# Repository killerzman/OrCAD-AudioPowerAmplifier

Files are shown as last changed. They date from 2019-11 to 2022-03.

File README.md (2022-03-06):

# OrCAD Audio Power Amplifier 

OrCAD project of an audio power amplifier implementation. This remained only at a concept stage and was never physically created.

This project was made in year 3 of my university studies at Politehnica University of Bucharest @ Faculty of Electronics, Telecommunications and Information Technology

The implementation was a bit **rushed and unorganized** and some of the documentation is in **Romanian** so **browse at your own risk!**

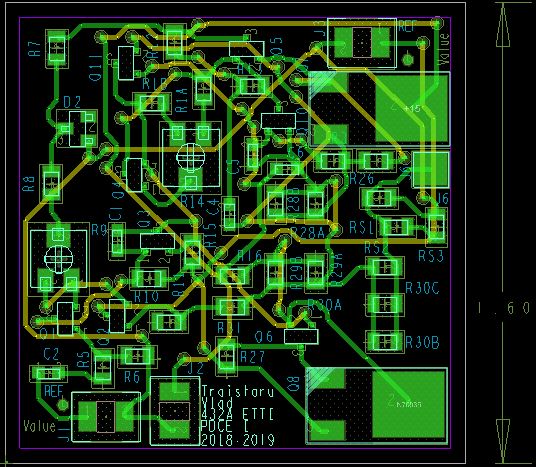
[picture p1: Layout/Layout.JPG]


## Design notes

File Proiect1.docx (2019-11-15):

Trăistaru Vlad-Viorel

Grupa 432A

Amplificatorul audio de putere

PROIECT 1 DCE ETTI

#### AMPLIFICATORUL AUDIO DE PUTERE

Acest capitol prezintă principalele aspectele ale proiectării amplificatoarelor audio de putere. Se porneşte de la o temă de proiectare care stabileşte schema bloc a amplificatorului şi principalii parametri ai amplificatorului. După proiectarea etajului final, pilot, diferenţial, a protecţiei termice şi la scurtcircuit sunt analizate stabilitatea şi amplificarea stabilită de reţeaua de reacţie negativă.

# 1. TEMA DE PROIECTARE

Tema de proiectare se referă la un amplificator de audiofrecvenţă de mare putere realizat dintr-un etaj de ieşire în clasă B polarizat cu ajutorul etajului pilot care lucrează în clasă A. Pentru asigurarea unui curent mare de ieşire tranzistoarele finale sunt realizate din două tranzistoare în conexiune darlington.

Amplificarea în tensiune şi adaptarea cu sursa de semnal de intrare este realizată cu ajutorul etajului de intrare de tip diferenţial care lucrează de asemenea în clasă A. Amplificarea globală a amplificatorului este stabilită prin intermediul reacţiei negative.

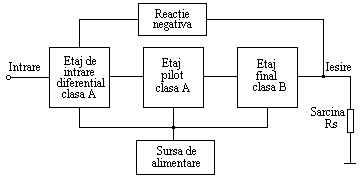
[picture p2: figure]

Figura 2.1 Schema bloc a amplificatorului audio de putere

# 2. SETURI DE DATE DE INTRARE

Principalii parametri ai amplificatorului audio de putere sunt:

- Puterea nominală pe sarcină PS (W)
- Rezistenţa de sarcină Rs (Ω)
- Rezistenţa de intrare Ri (KΩ)
- Amplificarea în tensiune Au (-)

Sursa de alimentare va asigura următorii parametri:

- Curentul nominal Io (mA)
- Rezistenţa de ieşire Ro (Ω)
- Coeficientul de stabilizare
- Tensiunea de alimentare este 220Vac ± 10%

Tabelul 2.1 Seturi de date de intrare pentru proiectare

Nr. | Amplificator | | | | Sursa de alimentare
| PS (W) | Rs (Ω) | Ri (KΩ) | Au (-) | IoM (A) | RoM (Ω)
8 | 10 | 6 | 45 | 10 | 4.1 | 7.2

# 3. ETAJUL FINAL

Este realizat cu două tranzistoare bipolare complementare în conexiune colector comun. Deoarece tehnologia bipolară este axată pe tranzistore de putere de tip npn şi pentru creşterea amplificării în curent a etajului final se utilizează pentru cele două tranzistoare finale de putere configuraţii darlington de tip npn şi pnp.

Figura 2.2 Configuraţie darligton de tip npn

Considerăm T5 şi T7 în regim activ normal RAN.

VBE = VBE5 + VBE7 > 0

>0 >0

=> RAN

VCE = VCE7 = VCE5 + VBE7 > 0

Pentru ICB0 = 0 =>

Ic = Ic5 + Ic7 = βF5 Ib5 + βF7 Ib7 = βF5 Ib5 + βF7 Ie5 =

= = =

= =

≈ ≈

Principalii parametri ai configuraţiei Darlington de tip npn sunt:

βF ≈ βF7 βF5 = mare avantaj

== mare avantaj

VCE, Saturaţie = VCE2, Saturaţie = nemodificată avantaj

VBE = 2VBE5 = 2VBE7 = mare dezavantaj

Figura 2.3 Configuraţie darligton de tip pnp

Considerăm T1 şi T2 in RAN.

VEB = VEB6 > 0

=> RAN

VEC = VCE8 = VEC6 + VBE8 > 0

Pentru ICB0 = 0 =>

IC = IE8 = ( βF8 + 1 ) IB8 = ( βF8 + 1 ) IC6 =

= ( βF8 + 1 ) βF6 IB6 = ( βF8 + 1 ) βF6 IB

βF = (I_C)/(I_B) = ( βF8 + 1 ) βF6 ≈ βF8 βF6

Principalii parametri ai configuraţiei Darlington de tip pnp sunt:

βF ≈ βF8 βF6 = mare avantaj

h11 = h116 = nemodificat avantaj

VEB = VEB6 = nemodificat avantaj

VEC = VCE8 = VEC6 + VBE8 = mare dezavantaj

Când T6 se saturează se pierde controlul lui IC6 prin IB6 iar IC6 se închide prin joncţiunea BE a lui T8 care rămâne în RAN. =>

VEC, Saturaţie = VECT6, Saturaţie + VBET8 = 0,2 + 0,6 = 0,8V

Tehnologia bipolară standard este orientată pe fabricarea tranzistoarelor de tip npn care au conducţie verticală şi au factorul de amplificare în curent βF = mare (100 ÷ 200). Tranzistoarele pnp sunt de tip lateral cu conducţie orizontală sau tranzistor de substrat cu condiţie verticală având βF mic.

În practică se folosesc configuraţiile darlington cu rezistenţă în paralel cu joncţiunea bază-emitor a tranzistorului bipolar de putere de tip npn (R26 şi R27). Rolul acestor rezistenţe este următorul:

- La funcţionarea în clasă „B” în repaus curentul prin T7 este mic iar curentul de baza va fi şi el mic. La curenţi mici de colector amplificarea în curent a tranzistoarelor are o cădere pronunţată Þ amplificarea este redusă Þ reacţia negativă va fi ineficientă asupra neliniarităţii curbei de transfer. La îmbinarea caracteristicilor tranzistoarelor complementare apar distorsiuni de trecere (cross-over) şi pentru micşorarea acestora se face o polarizare iniţială în regim static al tranzistoarelor. Rezistenţa R26 măreşte curentul de colector al tranzistorului T5 în regim de repaus deoarece la IC7 mic ,h11T7 e foarte mare şi cea mai mare a curentului dat de T5 trece prin R26 si astfel T7 lucrează la curenţi acceptabili cu βF7 suficient de mare. La curenţi IC7 mari h11T7 scade exponenţial la creşterea curentului dat de T7 şi R26 se poate neglija.
- Rezistenţa R26 permite evacuarea sarcinii stocate prin circulaţia unui curent invers de bază în perioada corespunzătoare blocării Þ R26 îmbunătăţeşte funcţionarea la frecvenţe înalte dar nu elimină efectele dacă frecvenţa de lucru e mai mare ca fβ.

##### Puterea disipată de tranzistorii finali T7,T8

##### Puterea maximă ce se poate obţine la ieşire este:

##### P_0 =E_C ⋅I_(CM)

EC este tensiunea de alimentare pentru un tranzistor final

ICM este curentul de colector maxim al tranzistorilor finali

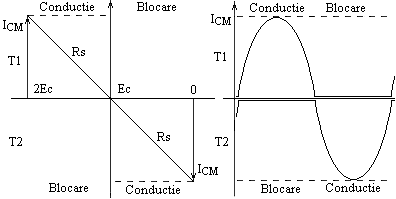
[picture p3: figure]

Figura 2.4 Diagramele de funcţionare a etajului final în contratimp

Puterea absorbită de la sursa de alimentare este:

P_a =2E_C ⋅I_(med)

Imed este curentul mediu absorbit de la sursă

Imed = = k

k este factorul de utilizare a tensiunii de alimentare

P_a =2E_C ⋅I_(med) =2E_C ⋅k⋅(I_(CM))/π=(2k)/π⋅P_0 =0,636⋅k⋅P_0

Puterea nominală pe sarcină are expresia:

P_S =1/2⋅R_S ⋅(k⋅I_(CM) )^2 =1/2⋅R_S ⋅k^2 ⋅I^2 _(CM) =0,5⋅k^2 ⋅P_0

RS este rezistenţa de sarcină

Puterea disipată de tranzistorii finali este:

P_(d(T_7 +T_8 )) =P_a -P_u =(0,636k-0,5k^2 )⋅P_0

Randamentul η=(P_S)/(P_a)=(0,5⋅k^2 ⋅P_0)/(0,636⋅k⋅P_0)=0,785⋅k

Derivând expresia puterii disipate de tranzistorii finali în raport cu k Þ puterea disipată maximă pe tranzistorii finali P_(dmax(T7+T8)) la k=0,636.

Pentru k=0,636 Þ

P_(dmax(T7+T8)) =[0,636^2 -0,5⋅(0,636)^2 ]⋅P_0 =0,2⋅P_0

Pentru un singur tranzistor final

P_(dmaxT7,T8) =1/2⋅(0,636⋅k-0,5⋅k^2 )⋅P_0 , pentru k=0.636 Þ

P_(dmaxT7,T8) =0,1⋅P_0

###### Dimensionarea componentelor etajului final

Pentru dimensionarea componentelor etajului final se impun condiţiile:

- Puterea nominală pe sarcină PS la o frecvenţă convenabilă, respectiv 1kHz (din setul de date utilizate pentru exemplificare PS =60)
- Impedanţa de sarcină nominală la 1kHz are caracter predominant rezistiv RS (din setul de date utilizate pentru exemplificare RS =4Ω)

1. Determinarea valorilor de vârf ale curentului şi tensiunii pe sarcină

P_S =(I_S 2 ⋅R_S)/2=(I_S ⋅U_S)/2⇒I_S =√((2⋅P_S)/(R_S))=√((2⋅10)/6)=1,82A

U_S =R_S ⋅I_S =6Ω⋅1,82A=12,64V≈10,9V

2. Se admite o pierdere de putere de maxim 10% pe rezistenţele de emitor R28 şi R29

R_28 =R_29 =0,47Ω < 0.1 X 6Ω

toleranţă ± 1%

Căderea maximă de tensiune pe R28, R29 este

U_(R_28) =U_(R_29) =R_28 ⋅I_S =0,47 ⋅ 1,82A = 0,85V

P_(dR28,R29) =(I_S ⋅U_(R_28))/4=0,38W (valoare medie, T7,T8 lucrează în clasă B). Se aleg R28 şi R29 de 0,5W (4x 0,125 W fiecare).

3. Se alege rezistenţa pentru circuitul de protecţie la suprasarcină

R_30 =0,157Ω U_(R30) =R_30 ⋅I_S =0,28V P_(dR30) =(Is⋅U_(R30))/2=0,26W

Se alege R30 de 0.375W (3x 0.125W fiecare).

4. Se aleg tranzistorii finali

S-a optat pentru tranzistori finali bipolari de putere de tip MJD31C având următorii parametri:

P_(tot) =15W UCE0,UCER = 100V I_C =3A

h21E = 25-50 (la IC=2A) UBE < 1V UCES = 1.2V

ft = 3Mhz

Ptot este puterea totală disipată

UCE0 este tensiunea colector emitor cu baza în gol

UCER este tensiunea colector emitor cu rezistenţă specificată între bază şi emitor

IC este curentul de colector

h21E este factorul de amplificare în curent static în conexiunea emitor comun

UBE este tensiunea bază emitor

UCES este tensiunea colector emitor în saturaţie

ft este frecventa de taiere minima

5. Verificarea la străpugere a trnzistorilor finali

EC ≤ 0,9UCER , EC = 14V ≤ 90= 0,9 VCER

6. Determinarea tensiunii reziduale pe darlingtonul npn

Urez = UCEST5 + UBET7max

În cazul cel mai defavorabil:

β_(T7,T8) =25⇒I_(BT7,T8) =(I_(CT7,T8))/(β_(T7,T8))=(I_S)/(β_(T7,T8))=(1,82A)/25=72,8mA

În funcţie de IBT7,T8 se aleg T5 şi T6 (BC846B, BC856B)

Pentru BC846B, UCEST5 ≈ 0,4V Þ Urez = 0,4 + 1= 1,4V

7. Determinarea tensiunii de alimentare

EC ≥ US + UR30 + UR28 + Urez = 13.005V = EC’

Se alege EC = 14V > EC’

8. Calculul energetic al tranzistorilor finali

P_0 =E_C ⋅I_(CM) =E_C ⋅I_S =25,48W k=(E^(') _C)/(E_C)=13/14=0,92 P_a =0,636⋅k⋅P_0 =14,9W P_S =1/2⋅k^2 ⋅P_0 =10,78W P_d =P_a -P_S =4,12W

(Puterea disipată pe T7 si T8 )

Puterea disipată pe un tranzistor final este maximă pentru k=0,636 este

P_(dmaxT_7) =P_(dmaxT_8) =0,1⋅P_0 =2,54W

În cazul nostru pentru k=0,92 puterea disipată pe un tranzistor final este

PdT7,T8 = 0,5 ( 0,636k – 0,5 k² ) P0 = 2,06W

η=0,785⋅k=0,722

9.Dimensionarea rezistenţelor R26 ,R27

Se aleg R26 ,R27 = 51Ω, toleranţă ± 1%

ICMT5 = IBMT7 + IR26 = IBMT7 + =72,8 mA + (1V)/(51Ω) ≈92,4mA<100mA

ICMT5 este curentul de colector maxim al tranzistorului T5

IBMT7 este curentul de bază maxim al tranzistorului T7

UBRMT7 este tensiunea bază emitor a tranzistorului T7

10. Estimarea sarcini dinamice pentru T5,T6

RST5 = [ h11T7 + βT7 ( RS + R30 + R28 ) ] ║ R_26

h11T7 = (U_(BEMT7))/(I_(BT7)) ≅ 13,7 Ω

RST5 = ( 13,7 + 25 · 6,627 ) ║ 51 = 39,6 Ω

11. Calculul energetic al tranzistorilor complementari

P0 = ICMT5 · EC = 0,0924· 14 = 1,29W

P0_(dmax) =0.1 P0 =0,129W

Tranzistoarele BC846B şi BC856B corespund, având următorii parametri:

I_C =0.1A I_(CM) =0.2A Ib=5mA T_j =150^0 C P_(tot) =0.25W f_T =100MHz R_(th,j-C) ≤100C/W

12. Calculul frecventei de taiere

ωt = β×ωβ

Pentru T7 si T8 fβ ≥ 222-500kHz

Pentru T5 si T6 fβ ≥ 222-454kHz

# 4. ETAJUL PILOT

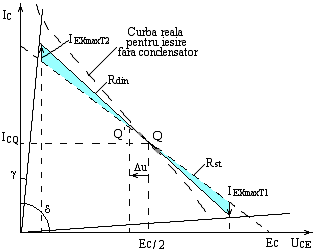
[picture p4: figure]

Figura 2.5 Configuraţia Figura 2.6 Caracteristica de ieşire

etajului pilot ale etajului pilot

Etajul pilot conform cu figura 2.5 este de tip emitor comun EC şi lucrează în clasa A. Pentru utilizarea completă a sursei de alimentare a circuitului de putere este necesară o tensiune de excitaţie vârf la vârf mai mare ca tensiunea de alimentare Uex,vv > EC, condiţie greu de realizat.

În figura 2.6 tgγ=R_(sat) si tgδ=R_(rez) , definite în raport cu ICER. Se observă că în cazul real excursia tensiunii Uex,vv este mult mai mică decât EC şi asimetrică.

K1 şi K2 sunt coeficienţii de utilizare ai tensiunii de alimentare pentru tranzistorul T1 respectiv pentru tranzistorul T2.

În schemele cu ieşire pe condensator, datorită inegalităţii dintre K1 şi K2 (în general K1 < K2) apar distorsiuni la nivele mari şi apare o componentă continuă ( Δu ) ce deplasează punctul static de funcţionare (PSF-ul) în sensul egalizării factorului de utilizare, figura 2.5. În schemele în care ieşirea nu se face pe condensator, ca în cazul acestui proiect, apare o curbură a caracteristicilor.

Soluţia poate fi folosirea unei tensiuni de alimentare a etajului pilot E_p >E_c , fapt ce conduce la complicarea surei de alimentare sau la soluţia de bustrapare a rezistenţei RC.

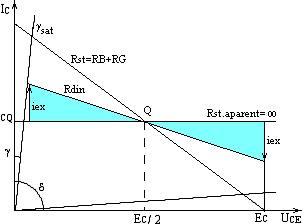
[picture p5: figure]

Figura 2.7 Bustraparea rezistenţei Figura 2.8 Caracteristica de ieşire

de colector a etajului pilot a etajului pilot butstrapat

Pentru acest montaj se poate considera:

- In regim static rezistenţa de alimentare este

R_(st) =R_c =R_B +R_G

- In regim dinamic ZS pentru etajul pilot este Rdin.
- In regim dinamic rezistenţa aparentă de alimentare este Rst a = ∞ şi sursa are valoarea E^(') _C =∞

Avantajele utilizării acestei soluţii sunt următoarele:

- Excursia curentului se limitează la

I_(VV) =2⋅I_(ex) <2⋅I_(CQ)

- Deoarece I_(CQ) >I_(ex) , această soluţie este avantajoasă pentru uşurarea regimului termic al etajului pilot.
- Se obţine astfel

k_1 ≈k_2

Condiţia de funcţionare a schemei este ca rezistenţa dinamică

R_(din) >R_C =R_B +R_G

###### Dimensionarea componentelor etajului pilot

1. Se calculează curentul de excitaţie maxim

I(I_(CT_5 max))/(β_(T_5 min) =(92,4mA)/220=0,42mA)BT_5 max_(exmax)

Se pot neglija curenţii reziduali şi se alege I_(CT3) =I_(CQ) =8mA > I_(exmax) =0,42mA

2. Rezistenţa statică de alimentare

R_C =R_B +R_G =R_13 +R_12 =(E_C)/(I_(CT_3))=(14V)/(8mA)=1,75KΩ

Alegem R_12 =910Ω si R_13 =1k

3. Sarcina dinamică a pilotului

R_(din) ≈(R_13 ⋅h_(11T_6))/(R_13 +h_(11T_6))+(1+h_(21E_f) ⋅(R_13)/(R_13 +h^(') _(11T_6)))(R_S +R_30 )

unde h11T6 = = 687,4Ω şi

h21Ef = h21T6 · h21T8 = 220· 25 = 5500

h^(') _(11T_6) =h_(11T_6) +(1+h_(21E_f) )⋅R_29 = 687,4+ ( 1+5500 ) · 0,47 = 3272,87Ω

Þ R_(din) =(1000⋅687,5)/(1687,5)+(1+5500⋅1/(1+3,2))⋅6.157≈8,476KΩ

Se verifică R_(din) =8,476kΩ>R_B +R_G =1,75KΩ

4. Tensiunea minimă pe tranzistorul pilot

UBEmin,T8_(CEmin,T6) _(pmin)

5. Alegerea tranzistorului pilot

Pentru o funcţionare cât mai bună a botstrapului se alege un tranzistor cu UCEsat şi ICER mici.

Se alege BC846B cu parametri:

I_C =0,1A I_(CM) =0,2A T_j =150^0 C P_(tot) =0,25W f_T =100MHz R_(th,j-C) ≤100C/W

La I_C =2⋅I_(CQ) =16mA→U_(CEsat) =0,6V si I_(CER) =0,2mA

Tensiunea ce trebuie preluata de R15 este

U_(R_15) =UCEsat,T3_15 (U_(R_15))/(I_(CQ))(0,2V)/(8mA)_(p_(min))

Calculele impun alegerea lui R15 = 33Ω cu toleranţă de 1%

6. Curentul de baza al tranzistorului T3

Considerând h21E mediu,T3 = 280 Þ

I_(BT3) =(8mA)/280=28μA

7. Verificarea funcţionării la semnal mic

μ_(BE) =(I_C)/(g_m)=(I_(ex))/(40I_(CQ))= 0,0235V =23.5mV < 26mV = (KT)/q

8. Amplificarea în tensiune a etajului pilot

Etajul pilot este de tip emitor comun cu sarcină distribuită având amplificarea în tensiune:

A_(μp) ≈-(R_(din))/(R_15)=-(8,476k)/(33Ω)=-256,84

9. Calculul frecvenţei de tăiere

ω_T =β_0 ⋅ω_β ⇒ f_(βT_3) ≥0,25..0,625MHz

###### 10. Calculul circuitului de polarizare al tranzistorilor finali

Circuitul de polarizare este alcătuit din tranzistorul T4 ( superdiodă ) şi potenţiometrul R14. Se consideră necesar pentru deschiderea tranzistorilor finali o tensiune de 2 × 0,7V.

Pentru tranzistorul T4 alegem tipul QBC846B având următoarele valori limită absolute:

VCE0 =65V IC = 100mA IB = 5mA

Ptot = 250mW

În PSF tranzistorul T4 are următorii parametri:

I_(C,T4) =8mA U_(CE,T4) ≅1,4V⇒I_(B,T4) =(I_(C,T4))/(h_(21E,T4))≅(8mA)/220=36μA

Se alege prin divizorul de bază curentul:

I_d ≅0,5mA>>I_(B,T4) ⇒R_14 =R_1 +R_2 =(1,4V)/(0,5mA)=2,8kΩ

Se alege R14’ = 2,64kΩ.

R14’ = R1A + R1B + R14(potentiometru)

R14 = 2,2kΩ, R1A = 220Ω, R1B = 220Ω

# 5. ETAJUL DIFERENŢIAL

Etajul diferenţial este alcătuit din două tranzistoare în conexiune EC care lucrează în clasă A şi sunt cuplate diferenţial. Componentele acestui etaj sunt următoarele:

- Tranzistoarele T1 ,T2
- Rezistentele R6, R8, R9, R11, R31 şi D1, R7

Principalele funcţii ale acestui etaj sunt:

- Obţinerea unei impedanţe de intrare convenabile.
- Reglează echilibrarea stării de repaus (în absenţa semnalului) a întregului amplificator de putere
- Permite cuplarea reţelei de reacţie negativă

###### Dimensionarea componentelor etajului diferenţial

1. Alegerea tranzistoarelor T1,T2

Tranzistoarele T1, T2 se aleg de tipul BC856B şi se împerechează (se sortează două tranzistoare cu caracteristici cât mai apropiate). Aceste tranzistoare au următoarele valori limită absolute:

VCE0 =65V IC = 100mA IB = 5mA

Ptot = 250mW Tj = 175°C

2. Dimensionarea rezistenţei de colector a tranzistorului T1 (R11)

Se alege R_(CT_1) =R_11 <Z_(inT3min)

Z21cT_3 _15 11cT_3 min_(inT3min)

IB,T3max ≅ (2I_(CT3))/(ℎ_(21E mediu,T3)) = (2⋅8)/280 = 57µA

IC,T3min ≅ IB,T3max = 57µA Þ = 40 · IC,T3min = 2,3 Þ

h11,T3min = = 160/(2,3) = 69.5K ≅ 70K

Þ Z21cT_3 _15 11cT_3 min_(inT3min) = 70K + 100·0,033K ≅ 103K

Pentru polarizarea bazei lui T3 trebuie ca :

(I_(C,T1) -I_(B,T3) )⋅R_11 =U_(BET3) +U_(R15) ≅ 0,7V + 8mA·33Ω ≅ 0,96V

Din motive de zgomot, pentru a avea factorul de zgomot F = 3dB trebuie ca:

ICT1 ≤ 300µA Se alege ICT1 = ICT2 = 250µA

Þ R_11 ≈(0,96)/(I_(C,T1) -I_(B,T3))=(0,96)/(250-57)=(0,96V)/(193mA)=4,9K

Se alege R11 = 5,6K cu toleranţă de ±1%.

3. Verificarea funcţionării la semnal mic

u_(BE,T1) =(i_(C,T1))/(g_(m,T1))=(i_(C,T1))/(40⋅I_(C,T1))=(80μA)/(40⋅250μA/V)=8mV

4. Determinarea tensiunii stabilizate de D1

Pentru a simula generatorul de curent din emitor trebuie ca tensiunea stabilizată U_z >>u_(BE,T1) . Deoarece I_(BT_1) e foarte mic se poate neglija tensiunea între bază şi masă.

Practic U_z =U_(R8) +U_(BE,T1) +U_(R6) ≈U_(R8) +U_(BE,T1)

Pentru ca R8 să se comporte ca un generator de curent continuu trebuie ca UR8 = ct, dar UBE,T1 variază cu uBE,T1 Þ tensiunea stabilizată de diodă trebuie să fie mult mai mare ca tensiunea bază emitor a tranzistorului T1, UZ >> UBE,T1.

Se alege UZ = 8,2V, astfel UZ ≅ 1000 · UBE,T1

Pentru tranzistorul T1 curentul de colector şi tensiunea colector emitor au valorile:

IC,T1 = 250µA şi U_(CE) ≈E_C =14V .

5. Dimensionarea rezistenţelor R6, R31

Se alege R6 = R31 = 47kΩ, ±5% având în vedere că în jurul acestei valori se va situa Zintr a întregului amplificator.

6. Dimensionarea rezistenţelor R9, R8

Pentru QBC856B din catalog se obţine h21E =220 Þ I_(B,T1) =(250μA)/220≈1μA .

Þ U_(R_6) =47mV . Considerând U_(BE,T1) ≈0,6V

Þ U_(1/2R9) +U_(R_8) =U_z -U_(BE,T1) -U_(R_6) =7,56V

Se alege pentru R9 o valoare de 500Ω şi atunci căderea de tensiune suplimentară pe jumătate din rezistenţa din emitorul lui T1 este :

U_(1/2R9) ≈I_(C,T1) ⋅1/2⋅R_9 =62,5mV Þ UR8 ≅ 7,5V

Curentul prin rezistenţa R8 este suma curenţilor de colector ai tranzistorilor T1, T2 IR8 = 2IC,T1 = 500µA Þ R_8 =(U_(R8))/(I_(R8))=(7,5V)/(0,5mA)=15K Ω, ±1%

7. Polarizarea diodei D1

Alegem o diodă zenner de tipul PL 8,2V care pentru o funcţionare normală trebuie polarizată la Iz =5mA.

R7 = (E_C -U_z)/(I_z +I_(R8))=(14V-8,2V)/(5,5mA) = 1,05KΩ

Se alege R7 = 1 kΩ, ±1%

8. Determinarea amplificării etajului diferenţial

Amplificarea etajului diferenţial poate fi aproximată astfel:

A_(udif) ≅-(R_(Sdif))/(1/2R_9) unde RSdif este rezistenţa de sarcină a diferenţialului

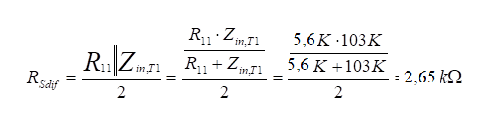
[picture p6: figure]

Þ A_(udif) ≅-(2,65)/(0,25) = -10,6 ≅ -11

# 6. REACŢIA NEGATIVĂ

Se apreciază un factor de transfer pe bucla de reacţie optim la frecvenţe medii:

β_r ≈(R_10)/(R_10 +R_31)≈1/10 (grad de reacţie ≈20dB )

Datorită divizoarelor protecţiei termice, tensiunea reală de intrare pe diferenţial este:

Uin,dif = D1 · D2 · Ugen

Unde: D1 = = 0,95 D2 = = 0,89

Se alege pentru Ugen = 1,5Vef Þ U_(in,dif) =0,95⋅0,89⋅1,5=1,3V_(ef)

Tensiunea nominală de ieşire este :

Un = = 0,7· IS· (RS + R30 ) = 0,7 · 1,82A · (6 + 0,157)Ω = 7,84V

Amplificarea cu reacţie este AUr = = (7,84)/(1,3) = 6,03 = = 1+

Þ = 5,03

Deoarece amplificarea în tensiune în buclă deschisă a amplificatorului de putere este dată de etajul pilot şi etajul diferenţial A_u ≈A_(up) ⋅A_(udif) =-126⋅(-11)=1,386

Practic A_(ur) ≅1/(β_r) Þ R10 ≅ (R_31)/11=(47KΩ)/11=4,27KΩ

Se adoptă R10 = 4,7KΩ, ±1%

Frecvenţa limită pentru T1 şi T2 este fβ ≥ 400 ÷ 800KHz

# 7. LISTA COMPONENTELOR

C1 : 47pF

C2,C3,C4 : 10uF

C5,C6 : 1nF

D2 : BZX84-C8V2

J1,J2,J3 : CON2

J6 : CON1

Q1,Q2,Q6,Q11 : QBC856B

Q3 : QBC817-25

Q4,Q5,Q10 : QBC846B

Q7,Q8 : QMJD31C

Rs1,R28B,R28A,R29B,R29A,R30C,R30B,R30A : 0.47Ω

Rs2 : 1Ω

Rs3 : 4.7Ω

R1B,R1A : 220Ω

R3,R7,R13,R16 : 1KΩ

R5,R14 : 2.2kΩ

R6,R31 : 47kΩ

R8 : 15kΩ

R9 : 500Ω

R10 : 4.7kΩ

R11 : 5.6kΩ

R12 : 910Ω

R15 : 33Ω

R26,R27 : 51Ω

# 8. SCHEMA ELECTRICĂ

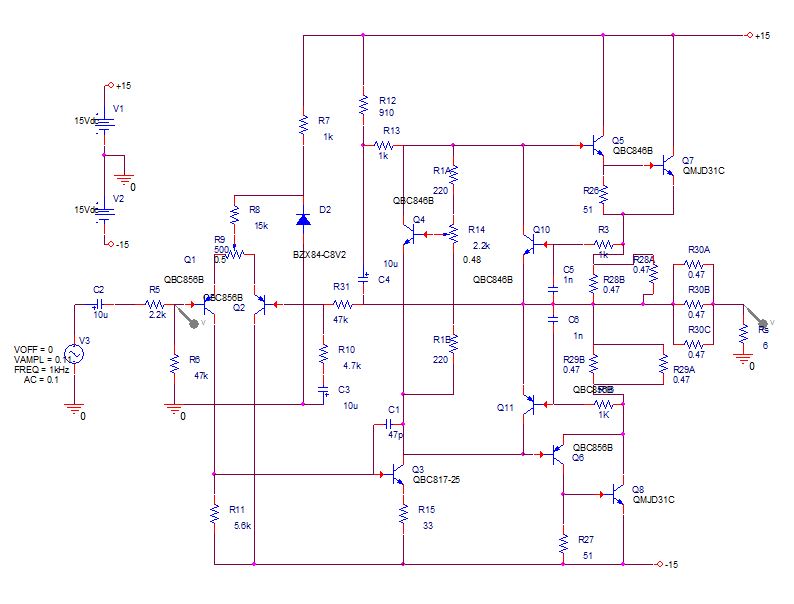
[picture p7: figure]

# 9. ANALIZĂ AC SWEEP

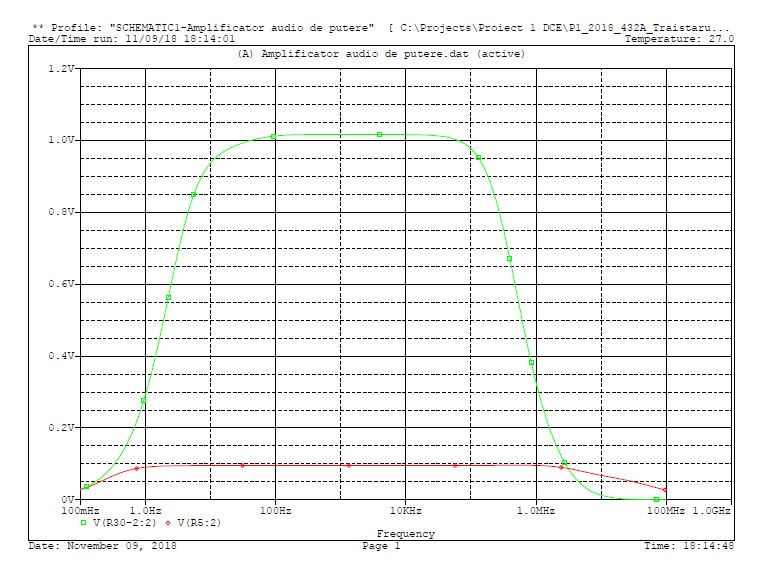
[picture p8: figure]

# 10. ANALIZĂ TIME DOMAIN

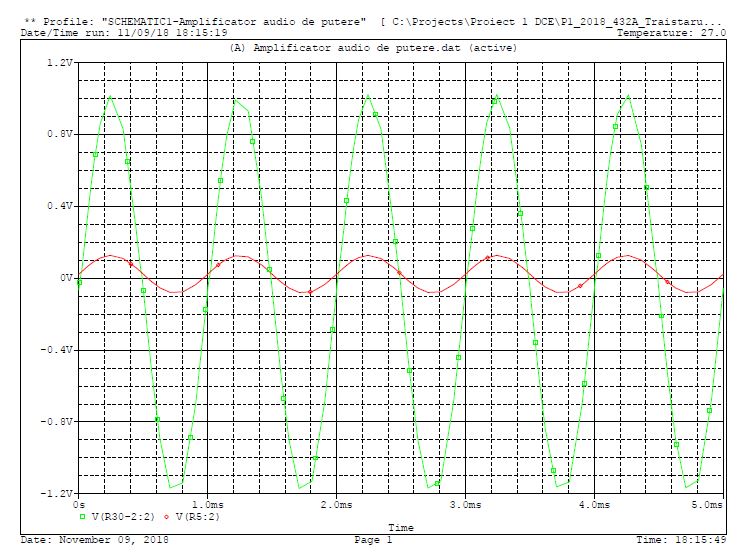
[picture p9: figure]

# 11. ANALIZĂ PSF

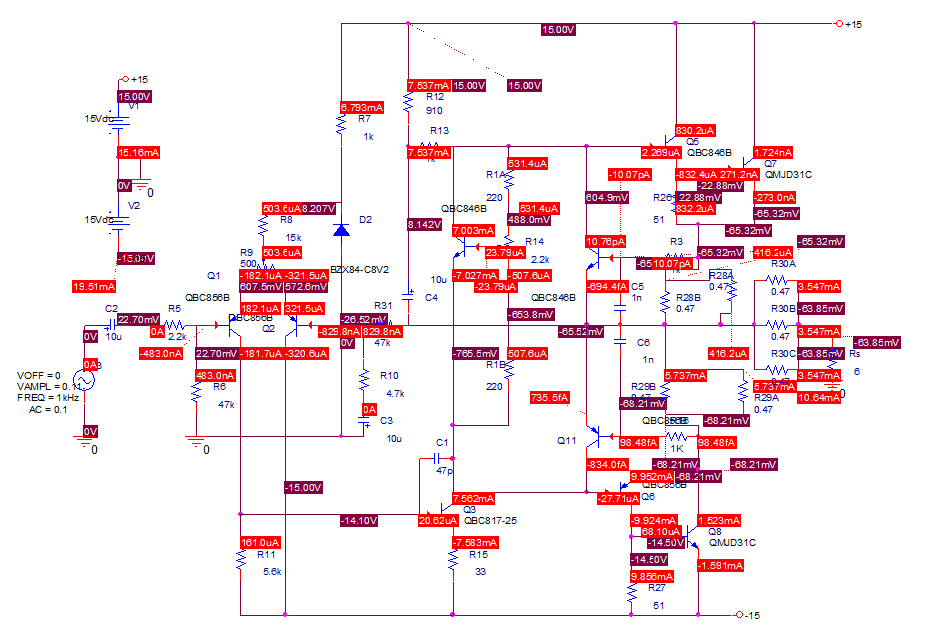
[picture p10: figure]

12. LAYOUT


Proiect 1 DCE ETTI – Amplificatorul audio de putere Trăistaru Vlad-Viorel – 432A

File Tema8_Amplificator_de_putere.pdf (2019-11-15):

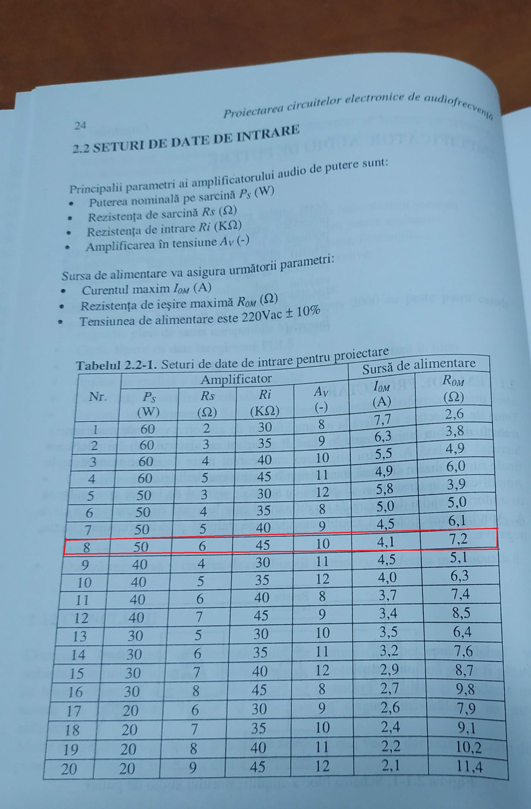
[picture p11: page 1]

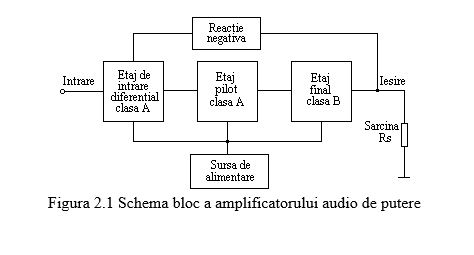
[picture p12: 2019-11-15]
Schema_bloc.JPG

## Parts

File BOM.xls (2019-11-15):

Anexa a1 -Componente SMD disponibile pentru realizarea proiectului P1- tehnlogie SMT- AU 2017-2018
Nr. Crt. | Nume | Catalog | Cod distrib | Nume prod | Prod | Clasă | Qty fix | Qty final | Qty min | Descriere | Distribuitor
1 | 0 ohm | (LINK) (http://www.tme.eu/ro/details/smd1206-0r/rezistente-smd-1206/royal-ohm/1206s4j0000t5e/) | 1206S4J0000T5E | 1206S4J0000T5E | SR PASSIVES | rezistor |  |  |  | Rezistor: thick film; SMD; 1206; 0Ω; 0,25W; ±5%; -55÷125°C | TME România
2 | 0.47 | (LINK) (http://www.tme.eu/ro/details/smd0805-0r47/rezistente-smd-0805/royal-ohm/0805s8j047kt5e/) | SMD0805-0R47 | 0805S8J047KT5E | ROYAL OHM | rezistor | 8 | 8 | 8 | Rezistor SMD, chip, 0805, 0.47Ω, ±5%, 0.125W | TME România
3 | 1 | (LINK) (http://www.tme.eu/ro/details/smd0805-1r-1%25/rezistente-smd-0805/royal-ohm/0805s8f100kt5e/) | SMD0805-1R-1% | 0805S8F100KT5E | ROYAL OHM | rezistor | 1 | 1 | 1 | Rezistor SMD, chip, 0805, 1Ω, ±1%, 0.125W | TME România
4 | 4.7 | (LINK) (http://www.tme.eu/ro/details/smd0805-4r7-1%25/rezistente-smd-0805/royal-ohm/0805waf-4r7-t5e/) | SMD0805-4R7-1% | 0805WAF 4R7 T5E | ROYAL OHM | rezistor | 1 | 1 | 1 | Rezistor SMD, chip, 0805, 4.7Ω, ±1%, 0.125W | TME România
5 | 10 | (LINK) (http://www.tme.eu/ro/details/smd0805-10r-1%25/rezistente-smd-0805/royal-ohm/0805s8f100jt5e/) | SMD0805-10R-1% | 0805S8F100JT5E | ROYAL OHM | rezistor |  |  |  | Rezistor SMD, chip, 0805, 10Ω, ±1%, 0.125W | TME România
6 | 22 | (LINK) (http://www.tme.eu/ro/details/smd0805-22r-1%25/rezistente-smd-0805/royal-ohm/0805s8f220jt5e/) | SMD0805-22R-1% | 0805S8F220JT5E | ROYAL OHM | rezistor |  |  |  | Rezistor SMD, chip, 0805, 22Ω, ±1%, 0.125W | TME România
7 | 33 | (LINK) (http://www.tme.eu/ro/details/smd0805-33r-1%25/rezistente-smd-0805/royal-ohm/0805s8f330jt5e/) | SMD0805-33R-1% | 0805S8F330JT5E | ROYAL OHM | rezistor | 1 | 1 | 1 | Rezistor SMD, chip, 0805, 33Ω, ±1%, 0.125W | TME România
8 | 51 | (LINK) (http://www.tme.eu/ro/details/rc0805jr-0751r/rezistente-smd-0805/yageo/rc0805jr-0751rl/) | SMD0805-51R-1% | 0805S8F510JT5E | ROYAL OHM | rezistor | 2 | 2 | 2 | Rezistor SMD, chip, 0805, 51Ω, ±1%, 0.125W | TME România
9 | 68 | (LINK) (http://www.tme.eu/ro/details/smd0805-68r-1%25/rezistente-smd-0805/royal-ohm/0805s8f680jt5e/) | SMD0805-68R-1% | 0805S8F680JT5E | ROYAL OHM | rezistor |  |  |  | Rezistor SMD, chip, 0805, 68Ω, ±1%, 0.125W | TME România
10 | 82 | (LINK) (https://www.tme.eu/ro/details/rc0805fr-0782r/rezistente-smd-0805/yageo/rc0805fr-0782rl/) | SMD0805-82R-1% | 0805S8F820JT5E | YAGEO | rezistor |  |  |  | Rezistor SMD, chip, 0805, 82Ω, ±1%, 0.125W | TME România
11 | 100 | (LINK) (http://www.tme.eu/ro/details/smd0805-100r-1%25/rezistente-smd-0805/royal-ohm/0805s8f1000t5e/) | SMD0805-100R-1% | 0805S8F1000T5E | ROYAL OHM | rezistor |  |  |  | Rezistor SMD, chip, 0805, 100Ω, ±1%, 0.125W | TME România
12 | 150 | (LINK) (https://www.tme.eu/ro/details/smd0805-150r/rezistente-smd-0805/royal-ohm/0805s8j0151t5e/) | SMD0805-150R-1% | 0805S8F1500T5E | ROYAL OHM | rezistor |  |  |  | Rezistor SMD, chip, 0805, 150Ω, ±1%, 0.125W | TME România
13 | 220 | (LINK) (http://www.tme.eu/ro/details/smd0805-220r-1%25/rezistente-smd-0805/royal-ohm/0805s8f2200t5e/) | SMD0805-220R-1% | 0805S8F2200T5E | ROYAL OHM | rezistor | 2 | 2 | 2 | Rezistor SMD, chip, 0805, 220Ω, ±1%, 0.125W | TME România
14 | 330 | (LINK) (http://www.tme.eu/ro/details/smd0805-330r-1%25/rezistente-smd-0805/royal-ohm/0805s8f3300t5e/) | SMD0805-330R-1% | 0805S8F3300T5E | ROYAL OHM | rezistor |  |  |  | Rezistor SMD, chip, 0805, 330Ω, ±1%, 0.125W | TME România
15 | 470 | (LINK) (http://www.tme.eu/ro/details/smd0805-470r-1%25/rezistente-smd-0805/royal-ohm/0805s8f4700t5e/) | SMD0805-470R-1% | 0805S8F4700T5E | ROYAL OHM | rezistor |  |  |  | Rezistor SMD, chip, 0805, 470Ω, ±1%, 0.125W | TME România
16 | 510 | (LINK) (https://www.tme.eu/ro/details/rc0805jr-07510r/rezistente-smd-0805/yageo/rc0805jr-07510rl/) | SMD0805-510R-5% | 0805S8J0511T5E | YAGEO | rezistor | 1 | 1 | 1 | Rezistor SMD, chip, 0805, 510Ω, ±5%, 0.125W | TME România
17 | 680 | (LINK) (http://www.tme.eu/ro/details/smd0805-680r-1%25/rezistente-smd-0805/royal-ohm/0805s8f6800t5e/) | SMD0805-680R-1% | 0805S8F6800T5E | ROYAL OHM | rezistor |  |  |  | Rezistor SMD, chip, 0805, 680Ω, ±1%, 0.125W | TME România
18 | 820 | (LINK) (http://www.tme.eu/ro/details/smd0805-820r-1%25/rezistente-smd-0805/royal-ohm/0805s8f8200t5e/) | SMD0805-820R-1% | 0805S8F8200T5E | ROYAL OHM | rezistor |  |  |  | Rezistor SMD, chip, 0805, 820Ω, ±1%, 0.125W | TME România
19 | 910 | (LINK) (https://www.tme.eu/ro/details/smd0805-910r-1%25/rezistente-smd-0805/royal-ohm/0805s8f9100t5e/) | SMD0805-910R-5% | 0805WAJ 910R T5E | ROYAL OHM | rezistor | 1 | 1 | 1 | Rezistor SMD, chip, 0805, 910Ω, ±5%, 0.125W | TME România
20 | 1k | (LINK) (http://www.tme.eu/ro/details/smd0805-1k-1%25/rezistente-smd-0805/royal-ohm/0805s8f1001t5e/) | SMD0805-1K-1% | 0805S8F1001T5E | ROYAL OHM | rezistor | 4 | 4 | 4 | Rezistor SMD, chip, 0805, 1kΩ, ±1%, 0.125W | TME România
21 | 1.5k | (LINK) (http://www.tme.eu/ro/details/smd0805-1k5-1%25/rezistente-smd-0805/royal-ohm/0805s8f1501t5e/) | SMD0805-1K5-1% | 0805S8F1501T5E | ROYAL OHM | rezistor |  |  |  | Rezistor SMD, chip, 0805, 1.5kΩ, ±1%, 0.125W | TME România
22 | 1.8k | (LINK) (http://www.tme.eu/ro/details/smd0805-1k8-1%25/rezistente-smd-0805/royal-ohm/0805s8f1801t5e/) | SMD0805-1K8-1% | 0805S8F1801T5E | ROYAL OHM | rezistor |  |  |  | Rezistor SMD, chip, 0805, 1.8kΩ, ±1%, 0.125W | TME România
23 | 2k | (LINK) (http://www.tme.eu/ro/details/smd0805-2k-1%25/rezistente-smd-0805/royal-ohm/0805s8f2001t5e/) | SMD0805-2K-1% | 0805S8F2001T5E | ROYAL OHM | rezistor |  |  |  | Rezistor SMD, chip, 0805, 2kΩ, ±1%, 0.125W | TME România
24 | 2.2k | (LINK) (http://www.tme.eu/ro/details/smd0805-2k2-1%25/rezistente-smd-0805/royal-ohm/0805s8f2201t5e/) | SMD0805-2K2-1% | 0805S8F2201T5E | ROYAL OHM | rezistor | 2 | 2 | 2 | Rezistor SMD, chip, 0805, 2.2kΩ, ±1%, 0.125W | TME România
25 | 2.7k | (LINK) (https://www.tme.eu/ro/details/smd0805-2k7/rezistente-smd-0805/royal-ohm/0805s8j0272t5e/) | SMD0805-2K7-1% | 0805S8F2701T5E | ROYAL OHM | rezistor |  |  |  | Rezistor SMD, chip, 0805, 2.7kΩ, ±1%, 0.125W | TME România
26 | 3.3k | (LINK) (http://www.tme.eu/ro/details/smd0805-3k3-1%25/rezistente-smd-0805/royal-ohm/0805s8f3301t5e/) | SMD0805-3K3-1% | 0805S8F3301T5E | ROYAL OHM | rezistor |  |  |  | Rezistor SMD, chip, 0805, 3.3kΩ, ±1%, 0.125W | TME România
27 | 3.9k | (LINK) (http://www.tme.eu/ro/details/smd0805-3k9-1%25/rezistente-smd-0805/royal-ohm/0805s8f3901t5e/) | SMD0805-3K9-1% | 0805S8F3901T5E | ROYAL OHM | rezistor |  |  |  | Rezistor SMD, chip, 0805, 3.9kΩ, ±1%, 0.125W | TME România
28 | 4.7k | (LINK) (http://www.tme.eu/ro/details/smd0805-4k7-1%25/rezistente-smd-0805/royal-ohm/0805s8f4701t5e/) | SMD0805-4K7-1% | 0805S8F4701T5E | ROYAL OHM | rezistor | 1 | 1 | 1 | Rezistor SMD, chip, 0805, 4.7kΩ, ±1%, 0.125W | TME România
29 | 5.6k | (LINK) (https://www.tme.eu/ro/details/rc0805jr-075k6/rezistente-smd-0805/yageo/rc0805jr-075k6l/) | SMD0805-5K6-1% | 0805S8F5601T5E | YAGEO | rezistor | 1 | 1 | 1 | Rezistor SMD, chip, 0805, 5.6kΩ, ±1%, 0.125W | TME România
30 | 6.8k | (LINK) (http://www.tme.eu/ro/details/smd0805-6k8-1%25/rezistente-smd-0805/royal-ohm/0805s8f6801t5e/) | SMD0805-6K8-1% | 0805S8F6801T5E | ROYAL OHM | rezistor |  |  |  | Rezistor SMD, chip, 0805, 6.8kΩ, ±1%, 0.125W | TME România
31 | 8.2k | (LINK) (http://www.tme.eu/ro/details/smd0805-8k2-1%25/rezistente-smd-0805/royal-ohm/0805s8f8201t5e/) | SMD0805-8K2-1% | 0805S8F8201T5E | ROYAL OHM | rezistor |  |  |  | Rezistor SMD, chip, 0805, 8.2kΩ, ±1%, 0.125W | TME România
32 | 9.1k | (LINK) (http://www.tme.eu/ro/details/smd0805-9k1-1%25/rezistente-smd-0805/royal-ohm/0805waf-9k1-t5e/) | SMD0805-9K1-1% | CRCW080510K0FKTABC | VISHAY | rezistor |  |  |  | Rezistor SMD, chip, 0805, 9.1kΩ, ±1%, 0.125W | TME România
33 | 10k | (LINK) (http://www.tme.eu/ro/details/crcw080510k0fktabc/rezistente-smd-0805/vishay/) | SMD0805-10K-1% | 0805S8F1002T5E | ROYAL OHM | rezistor |  |  |  | Rezistor SMD, chip, 0805, 10kΩ, ±1%, 0.125W | TME România
34 | 15k | (LINK) (http://www.tme.eu/ro/details/smd0805-15k-1%25/rezistente-smd-0805/royal-ohm/0805s8f1502t5e/) | SMD0805-15K-1% | 0805S8F1502T5E | ROYAL OHM | rezistor | 1 | 1 | 1 | Rezistor SMD, chip, 0805, 15kΩ, ±1%, 0.125W | TME România
35 | 22k | (LINK) (http://www.tme.eu/ro/details/smd0805-22k-1%25/rezistente-smd-0805/royal-ohm/0805s8f2202t5e/) | SMD0805-22K-1% | 0805S8F2202T5E | ROYAL OHM | rezistor |  |  |  | Rezistor SMD, chip, 0805, 22kΩ, ±1%, 0.125W | TME România
36 | 47k | (LINK) (http://www.tme.eu/ro/details/smd0805-47k/rezistente-smd-0805/royal-ohm/0805s8j0473t5e/) | 0805S8J0473T5E | 0805S8J0473T5E | ROYAL OHM | rezistor | 2 | 2 | 2 | Rezistor: thick film; SMD; 0805; 47kΩ; 0,125W; ±5%; -55÷125°C | TME România
37 | 68k | (LINK) (http://www.tme.eu/ro/details/rc0805jr-0768k/rezistente-smd-0805/yageo/rc0805jr-0768kl/) | SMD0805-68K-5% | RC0805JR-0768KL | Yageo | rezistor |  |  |  | Rezistor SMD, chip, 0805, 68kΩ, ±5%, 0.125W | TME România
38 | 100k | (LINK) (http://www.tme.eu/ro/details/smd0805-100k-1%25/rezistente-smd-0805/royal-ohm/0805s8f1003t5e/) | SMD0805-100K-1% | 0805S8F1003T5E | ROYAL OHM | rezistor |  |  |  | Rezistor SMD, chip, 0805, 100kΩ, ±1%, 0.125W | TME România
39 | 150k | (LINK) (http://www.tme.eu/ro/details/smd0805-150k/rezistente-smd-0805/royal-ohm/0805s8j0154t5e/) | SMD0805-150K-5% | 0805S8J0154T5E | ROYAL OHM | rezistor |  |  |  | Rezistor SMD, chip, 0805, 150kΩ, ±5%, 0.125W | TME România
40 | 180k | (LINK) (http://www.tme.eu/ro/details/smd0805-180k/rezistente-smd-0805/royal-ohm/0805s8j0184t5e/) | SMD0805-180K-5% | 0805S8J0184T5E | ROYAL OHM | rezistor |  |  |  | Rezistor SMD, chip, 0805, 180kΩ, ±5%, 0.125W | TME România
41 | 220k | (LINK) (http://www.tme.eu/ro/details/smd0805-220k-1%25/rezistente-smd-0805/royal-ohm/0805s8f2203t5e/) | SMD0805-220K-1% | 0805S8F2203T5E | ROYAL OHM | rezistor |  |  |  | Rezistor SMD, chip, 0805, 220kΩ, ±1%, 0.125W | TME România
42 | 330k | (LINK) (http://www.tme.eu/ro/details/smd0805-330k-1%25/rezistente-smd-0805/royal-ohm/0805s8f3303t5e/) | SMD0805-330K-1% | 0805S8F3303T5E | ROYAL OHM | rezistor |  |  |  | Rezistor SMD, chip, 0805, 330kΩ, ±1%, 0.125W | TME România
43 | 390k | (LINK) (http://www.tme.eu/ro/details/smd0805-390k-1%25/rezistente-smd-0805/royal-ohm/0805s8f3903t5e/) | SMD0805-390K-1% | 0805S8F3903T5E | ROYAL OHM | rezistor |  |  |  | Rezistor SMD, chip, 0805, 390kΩ, ±1%, 0.125W | TME România
44 | 510k | (LINK) (http://www.tme.eu/ro/details/smd0805-510k-1%25/rezistente-smd-0805/royal-ohm/0805s8f5103t5e/) | SMD0805-510K-1% | 0805S8F5103T5E | ROYAL OHM | rezistor |  |  |  | Rezistor SMD, chip, 0805, 510kΩ, ±1%, 0.125W | TME România
45 | 1M | (LINK) (http://www.tme.eu/ro/details/smd0805-1m/rezistente-smd-0805/royal-ohm/0805s8j0105t5e/) | SMD0805-1M | 0805S8J0105T5E | ROYAL OHM | rezistor |  |  |  | Rezistor SMD, chip, 0805, 1MΩ, ±1%, 0.125W | TME România
46 | 2M | (LINK) (http://www.tme.eu/ro/details/smd0805-2m/rezistente-smd-0805/royal-ohm/0805waj-2m-t5e/) | SMD0805-2M7 | 0805WAJ 2M T5E | ROYAL OHM | rezistor |  |  |  | Rezistor SMD, chip, 0805, 2MΩ, ±1%, 0.125W | TME România
47 | 5M | (LINK) (http://www.tme.eu/ro/details/smd0805-5m1/rezistente-smd-0805/royal-ohm/0805s8j0515t5e/) | SMD0805-5M1 | RC0805FR-075M1 | Yageo | rezistor |  |  |  | Rezistor SMD, chip, 0805, 5.1MΩ, ±1%, 0.125W | TME România
48 | 10M | (LINK) (http://www.tme.eu/ro/details/hp05-10m5%25/rezistente-smd-0805/royal-ohm/hp05w3j0106t5e/) | SMD0805-10M | HP05W3J0106T5E | ROYAL OHM | rezistor |  |  |  | Rezistor SMD, chip, 0805, 10MΩ, ±5%, 0.125W | TME România
49 | 100ohm | (LINK) (http://www.tme.eu/ro/details/1804gsmd-100r/trimere-smd-cu-o-singura-tura/sr-passives/) | 1804GSMD-100R | 1804GSMD-100R | SR PASSIVES | potențiometru |  |  |  | Potențiome-tru liniar, simplă tură, SMD, 100Ω, ±10%, 100ppm/°C, 0.25W | TME România
50 | 500ohm | (LINK) (https://www.tme.eu/ro/details/ts53yl500r/trimere-smd-cu-o-singura-tura/vishay/ts53yl501mr10/) | 1804GSMD-500R | 1804GSMD-500R | VISHAY | potențiometru | 1 | 1 | 1 | Potențiome-tru liniar, simplă tură, SMD, 500Ω, ±10%, 100ppm/°C, 0.25W | TME România
51 | 2k | (LINK) (https://www.tme.eu/ro/details/ts53yl2k/trimere-smd-cu-o-singura-tura/vishay/ts53yl202mr10/) | TS53YL202MR10 | TS53YL202MR10 | VISHAY | potențiometru | 1 | 1 | 1 | Potențiome-tru liniar, simplă tură, SMD, 2kΩ, ±20%, 100ppm/°C, 0.25W | TME România
52 | 5k | (LINK) (http://www.tme.eu/ro/details/3314g-1-502e/trimere-smd-cu-o-singura-tura/bourns/) | 3314G-1-502E | 3314G-1-502E | BOURNS | potențiometru |  |  |  | Potențiome-tru liniar, simplă tură, SMD, 5kΩ, ±20%, 100ppm/°C, 0.25W | TME România
53 | 10k | (LINK) (http://www.tme.eu/ro/details/3314g-1-103e/trimere-smd-cu-o-singura-tura/bourns/) | 3314G-1-103E | 3314G-1-103E | BOURNS | potențiometru |  |  |  | Potențiome-tru liniar, simplă tură, SMD, 10kΩ, ±20%, 100ppm/°C, 0.25W | TME România
54 | 50k | (LINK) (http://www.tme.eu/ro/details/3314g-1-503e/trimere-smd-cu-o-singura-tura/bourns/) | 3314G-1-503E | 3314G-1-503E | BOURNS | potențiometru |  |  |  | Potențiome-tru liniar, simplă tură, SMD, 50kΩ, ±20%, 100ppm/°C, 0.25W | TME România
55 | 100k | (LINK) (http://www.tme.eu/ro/details/ts53yl100k/trimere-smd-cu-o-singura-tura/vishay/ts53yl104mr10/) | TS53YL104MR10 | TS53YL104MR10 | VISHAY | potențiometru |  |  |  | Potențiome-tru liniar, simplă tură, SMD, 100kΩ, ±20%, 100ppm/°C, 0.25W | TME România
56 | 500k | (LINK) (http://www.tme.eu/ro/details/3314g-1-504e/trimere-smd-cu-o-singura-tura/bourns/) | 3314G-1-504E | 3314G-1-504E | BOURNS | potențiometru |  |  |  | Potențiome-tru liniar, simplă tură, SMD, 500kΩ, ±10%, 100ppm/°C, 0.25W | TME România
 | TOTAL - Componente pasive (rezistoare de valori fixe şi reglabile) |  |  |  |  |  |  |  |  | FARA TVA = | 6.75162
57 | 4.7pF | (LINK) (http://www.tme.eu/ro/details/cc0805crnpo94r7/condensatoare-mlcc-smd-0805/yageo/cc0805crnpo9bn4r7/) | CC0805CRNPO9BN4R7 | CC0805CRNPO9BN4R7 | YAGEO | condensator |  |  |  | ceramic; MLCC; 4,7pF; 50V; C0G; ±0,25pF; SMD; 0805 | TME România
58 | 10pF | (LINK) (http://www.tme.eu/ro/details/cc0805jrnpo9100/condensatoare-mlcc-smd-0805/yageo/cc0805jrnpo9bn100/) | CC0805JRNPO9BN100 | CC0805JRNPO9BN100 | YAGEO | condensator |  |  |  | ceramic; MLCC; 10pF; 50V; C0G; ±5%; SMD; 0805 | TME România
59 | 47pF | (LINK) (http://www.tme.eu/ro/details/cl21c470jbannnc/condensatoare-mlcc-smd-0805/samsung/) | CL21C470JBANNNC | CL21C470JBANNNC | SAMSUNG | condensator | 1 | 1 | 1 | Condensator: ceramic; MLCC; 47pF; 50V; C0G; ±5%; SMD; 0805; -55÷125°C | TME România
60 | 100pF | (LINK) (http://www.tme.eu/ro/details/cl21c101jbannnc/condensatoare-mlcc-smd-0805/samsung/) | CL21C101JBANNNC | CL21C101JBANNNC | SAMSUNG | condensator |  |  |  | Condensator: ceramic; MLCC; 100pF; 50V; C0G; ±5%; SMD; 0805 | TME România
61 | 470pF | (LINK) (http://www.tme.eu/ro/details/cl10b471kb8nnnc/condensatoare-mlcc-smd-0603/samsung/) | CL10B471KB8NNNC | CL10B471KB8NNNC | SAMSUNG | condensator |  |  |  | Condensator: ceramic; MLCC; 470pF; 50V; X7R; ±10%; SMD; 0603 | TME România
62 | 1nF | (LINK) (http://www.tme.eu/ro/details/c0805c102j5gac/condensatoare-mlcc-smd-0805/kemet/) | C0805C102J5GAC | C0805C102J5GAC | KEMET | condensator | 2 | 2 | 2 | Condensator MLCC, SMD, 0805, 1nF, ±5%, 50V, C0G | TME România
63 | 2.2nF | (LINK) (http://www.tme.eu/ro/details/cl21b222kbannnd/condensatoare-mlcc-smd-0805/samsung/) | CL21B222KBANNND | CL21B222KBANNND | SAMSUNG | condensator |  |  |  | Condensator: ceramic; MLCC; 2,2nF; 50V; X7R; ±10%; SMD; 0805 | TME România
64 | 4.7nF | (LINK) (http://www.tme.eu/ro/details/c0805c472k5rac/condensatoare-mlcc-smd-0805/kemet/) | C0805C472K5RAC | C0805C472K5RAC | KEMET | condensator |  |  |  | Condensator MLCC, SMD, 0805, 4.7nF, ±5%, 50V, X7R | TME România
65 | 5.6nF | (LINK) (http://www.tme.eu/ro/details/cl21b562kbannnc/condensatoare-mlcc-smd-0805/samsung/) | CL21B562KBANNNC | CL21B562KBANNNC | SAMSUNG | condensator |  |  |  | Condensator MLCC, SMD, 0805, 5.6nF, ±5%, 50V, X7R | TME România
66 | 10nF | (LINK) (http://www.tme.eu/ro/details/cl21b103kcannnc/condensatoare-mlcc-smd-0805/samsung/) | CL21B103KCANNNC | CL21B103KCANNNC | SAMSUNG | condensator |  |  |  | Condensator MLCC, SMD, 0805, 10nF, ±5%, 50V, X7R | TME România
67 | 22nF | (LINK) (http://www.tme.eu/ro/details/cl21b223kcfnnne/condensatoare-mlcc-smd-0805/samsung/) | CL21B223KCFNNNE | CL21B223KCFNNNE | SAMSUNG | condensator |  |  |  | Condensator: ceramic; MLCC; 22nF; 100V; X7R; ±10%; SMD; 0805 | TME România
68 | 33nF | (LINK) (http://www.tme.eu/ro/details/cl21b333kbannnc/condensatoare-mlcc-smd-0805/samsung/) | CL21B333KBANNNC | CL21B333KBANNNC | SAMSUNG | condensator |  |  |  | Condensator: ceramic; MLCC; 33nF; 50V; X7R; ±10%; SMD; 0805 | TME România
69 | 100nF | (LINK) (http://www.tme.eu/ro/details/cc0805krx7r9104/condensatoare-mlcc-smd-0805/yageo/cc0805krx7r9bb104/) | CC0805KRX7R9BB104 | CC0805KRX7R9BB104 | YAGEO | condensator |  |  |  | ceramic; MLCC; 100nF; 50V; X7R; ±10%; SMD; 0805 | TME România
70 | 220nF | (LINK) (http://www.tme.eu/ro/details/cl21b224kafnnne/condensatoare-mlcc-smd-0805/samsung/) | CL21B224KAFNNNE | CL21B224KAFNNNE | SAMSUNG | condensator |  |  |  | Condensator: ceramic; MLCC; 220nF; 25V; X7R; ±10%; SMD; 0805 | TME România
71 | 330nF | (LINK) (http://www.tme.eu/ro/details/08055c334kat2a/condensatoare-mlcc-smd-0805/avx/) | 08055C334KAT2A | 08055C334KAT2A | AVX | condensator |  |  |  | Condensator: ceramic; MLCC; 330nF; 50V; X7R; ±10%; SMD; 0805 | TME România
72 | 470nF | (LINK) (http://www.tme.eu/ro/details/cl21b474kbfnnng/condensatoare-mlcc-smd-0805/samsung/) | CL21B474KBFNNNG | CL21B474KBFNNNG | SAMSUNG | condensator |  |  |  | Condensator: ceramic; MLCC; 470nF; 50V; Y5V; -20÷+80%; SMD; 0805 | TME România
73 | 1uF | (LINK) (http://www.tme.eu/ro/details/cc0805kkx7r8105/condensatoare-mlcc-smd-0805/yageo/cc0805kkx7r8bb105/) | CC0805KKX7R8BB105 | CC0805KKX7R8BB105 | YAGEO | condensator |  |  |  | Condensator: ceramic; MLCC; 1uF; 25V; X7R; ±10%; SMD; 0805 | TME România
74 | 2.2uF | (LINK) (http://www.tme.eu/ro/details/grm219r61e225ka12d/condensatoare-mlcc-smd-0805/murata/) | GRM219R61E225KA12D | GRM219R61E225KA12D | MURATA | condensator |  |  |  | Condensator: ceramic; MLCC; 2,2uF; 25V; X5R; ±10%; SMD; 0805 | TME România
75 | 4.7uF | (LINK) (http://www.tme.eu/ro/details/cl21a475kaqnnne/condensatoare-mlcc-smd-0805/samsung/) | CL21A475KAQNNNE | CL21A475KAQNNNE | SAMSUNG | condensator |  |  |  | ceramic; MLCC; 4,7uF; 25V; X5R; ±10%; SMD; 0805 | TME România
76 | 10uF | (LINK) (http://www.tme.eu/ro/details/eeefk1j100p/condensatoare-electrol-smd-imped-joasa/panasonic/) | SC1H106M05005VR | SC1H106M05005VR | SAMWHA | condensator | 3 | 3 | 3 | Condensator: electrolitic; cu impedanţă redusă; SMD; 10uF; 63V | TME România
 | TOTAL - Componente pasive (condensatoare) |  |  |  |  |  |  |  |  | FARA TVA = | 2.06838
77 | 4148 | (LINK) (http://www.tme.eu/ro/details/1n4148-0805/diode-universale-smd/dc-components/cd4148ws0805c/) | 1N4148-0805 | CD4148WS(0805C) | DC Components | diodă pn |  |  |  | Diodă comutație, SMD, 0805, 300mA, 100V | TME România
78 | LED | (LINK) (http://www.tme.eu/ro/details/kp-2012src-prv/led-uri-smd-0805/kingbright-electronic/) | KP-2012SRC-PRV | KP-2012SRC-PRV | Kingbright Electronic | LED |  |  |  | LED roșu, SMD, 0805, 100mcd, 640nm, 120° | TME România
79 | 2.7V | (LINK) (http://www.tme.eu/ro/details/bzx84c2v7/diode-zener-smd/on-semiconductor/bzx84c2v7lt1g/) | BZX84C2V7 | BZX84-C2V7LT1G | ON Semiconductor | diodă Zener |  |  |  | Diodă Zener, SMD, SOT23, 2,7V, ±5%, 0.25W | TME România
80 | 5.1V | (LINK) (https://www.tme.eu/ro/details/bzx84-c5v1.215/diode-zener-smd/nexperia/) | BZX84C5V1 | BZX84-C5V1 | NEXPERIA | diodă Zener |  |  |  | Diodă Zener, SMD, SOT23, 5,1V, ±5%, 0.3W | TME România
81 | 5.6V | (LINK) (https://www.tme.eu/ro/details/bzx84c5v6-fai/diode-zener-smd/on-semiconductor-fairchild/bzx84c5v6/) | BZX84C5V6 | BZX84-C5V6 | ON Semiconductor | diodă Zener |  |  |  | Diodă Zener, SMD, SOT23, 5,6V, ±5%, 0.3W | TME România
82 | 6.2V | (LINK) (https://www.tme.eu/ro/details/bzx84-c6v2.215/diode-zener-smd/nexperia/) | BZX84C6V2 | BZX84-C6V2 | NEXPERIA | diodă Zener |  |  |  | Diodă Zener, SMD, SOT23, 6.2V, ±5%, 0.3W | TME România
83 | 6.8V | (LINK) (https://www.tme.eu/ro/details/bzx84-c6v8.215/diode-zener-smd/nexperia/) | BZX84C6V8 | BZX84-C6V8 | NEXPERIA | diodă Zener |  |  |  | Diodă Zener, SMD, SOT23, 6.8V, ±5%, 0.3W | TME România
84 | 8.2V | (LINK) (https://www.tme.eu/ro/details/bzx84-c8v2.215/diode-zener-smd/nexperia/) | BZX84C8V2 | BZX84-C8V2 | NEXPERIA | diodă Zener | 1 | 1 | 1 | Diodă Zener, SMD, SOT23, 8.2V, ±5%, 0.3W | TME România
85 | 10V | (LINK) (https://www.tme.eu/ro/details/bzx84-c10.215/diode-zener-smd/nexperia/) | BZX84C10 | BZX84-C10 | NEXPERIA | diodă Zener |  |  |  | Diodă Zener, SMD, SOT23, 10V, ±5%, 0.3W | TME România
86 | PNP | (LINK) (http://www.tme.eu/ro/details/bc856b-dio/tranzistori-smd-pnp/diotec-semiconductor/bc856b/) | BC856B | BC856B | DIOTEC | tranzistor bipolar | 4 | 4 | 4 | Tranzistor bipolar PNP, SMD, SOT23, 80V, 100mA | TME România
87 | NPN | (LINK) (http://www.tme.eu/ro/details/bc846b.215/tranzistori-smd-npn/nxp/) | BC846B | BC846B | NXP | tranzistor bipolar | 3 | 3 | 3 | Tranzistor bipolar NPN, SMD, SOT23, 65V, 100mA | TME România
89 | N-JFET | (LINK) (http://www.tme.eu/ro/details/mmbfj309lt1g/tranzistori-canal-n-smd/on-semiconductor/) | MMBFJ309LT1G | MMBFJ309LT1G | ON Semiconductor | tranzistor NJFET |  |  |  | Tranzistor N-JFET, SMD, SOT23, 25V, 30mA | TME România
90 | P-JFET | (LINK) (http://www.tme.eu/ro/details/mmbfj177lt1g/tranzistori-canal-p-smd/on-semiconductor/) | MMBFJ177LT1G | MMBFJ177LT1G | ON Semiconductor | tranzistor PJFET |  |  |  | Tranzistor P-JFET, SMD, SOT23, 30V, 20mA | TME România
91 | NPN | (LINK) (http://www.tme.eu/ro/details/bc817-25-dio/tranzistori-smd-npn/diotec-semiconductor/bc817-25/) | BC817-25-DIO | BC817-25-DIO | NXP | tranzistor bipolar | 1 | 1 | 1 | Tranzistor bipolar NPN, SMD, SOT23, 45V, 800mA | TME România
93 | PNP | (LINK) (http://www.tme.eu/ro/details/bc807-25-dio/tranzistori-smd-pnp/diotec-semiconductor/bc807-25/) | BC807-25-DIO | BC807-25-DIO | NXP | tranzistor bipolar |  |  |  | Tranzistor bipolar PNP, SMD, SOT23, 45V, 800mA | TME România
94 | NPN | (LINK) (http://www.tme.eu/ro/details/mjd31cg/tranzistori-smd-npn/on-semiconductor/) | MJD31CG | MJD31CG | ON Semiconductor | tranzistor bipolar | 2 | 2 | 2 | Tranzistor bipolar NPN, SMD, DPACK, 100V, 3A, 15W | TME România
96 | PNP | (LINK) (http://www.tme.eu/ro/details/mjd32cg/tranzistori-smd-pnp/on-semiconductor/) | MJD32CG | MJD32CG | ON Semiconductor | tranzistor bipolar |  |  |  | Tranzistor bipolar PNP, SMD, DPACK, 100V, 3A, 15W | TME România
97 | Nmos | (LINK) (http://www.tme.eu/ro/details/irfr120npbf/tranzistori-canal-n-smd/international-rectifier/) | IRFR120NPBF | IRFR120NPBF | International Rectifier | tranzistor NMOS |  |  |  | Tranzistor N-MOSFET, SMD, DPAK, 100V, 9.1A, 20V, 39W | TME România
 | TOTAL - Componente semiconductoare (tranzistoare bipolare şi cu efect de câmp, diode, LED, etc.) |  |  |  |  |  |  |  |  | FARA TVA = | 2.15053
98 | Conn2p | (LINK) (http://www.tme.eu/ro/details/zl301-40p/pini-cu-benzi-si-soclu/ninigi/) | ZL301-40P | ZL301-40P | NINIGI | Sir pini, pas 2,54mm, SMD | 3 | 3 | 3 | Sir pini, pas 2,54mm, SMD, tip tata, bareta de 40 pini | TME România
99 | FUSE | (LINK) (http://www.tme.eu/ro/details/3413.0116.11/sigurante-smd-1206-ultrarapide/schurter/) | 3413.0116.11 | 3413.0116.11 | SCHURTER | sigu-ranță | 0 | 0 | 0 | Siguranță sticlă, SMD, 1206, 1.25A, 48mΩ | TME România
 | Total - Conectică, sigurante fuzibile, etc. |  |  |  |  |  |  |  |  | FARA TVA = | 8.0565
 | Total general |  |  |  |  |  |  |  |  | FARA TVA = | 19.02703

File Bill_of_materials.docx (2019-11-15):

Revised: Friday, November 09, 2018

Revision:

Bill Of Materials November 9,2018 18:55:54 Page1

Item Quantity Reference Part

______________________________________________

1 1 C1 47p

2 3 C2,C3,C4 10u

3 2 C5,C6 1n

4 1 D2 BZX84-C8V2

5 3 J1,J2,J3 CON2

6 1 J6 CON1

7 4 Q1,Q2,Q6,Q11 QBC856B

8 1 Q3 QBC817-25

9 3 Q4,Q5,Q10 QBC846B

10 2 Q7,Q8 QMJD31C

11 8 Rs1,R28B,R28A,R29B,R29A, 0.47

R30C,R30B,R30A

12 1 Rs2 1

13 1 Rs3 4.7

14 2 R1B,R1A 220

15 4 R3,R7,R13,R16 1K

16 2 R5,R14 2.2k

17 2 R6,R31 47k

18 1 R8 15k

19 1 R9 500

20 1 R10 4.7k

21 1 R11 5.6k

22 1 R12 910

23 1 R15 33

24 2 R26,R27 51

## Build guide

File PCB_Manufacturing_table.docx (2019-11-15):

General info document for PCB manufacturing
No. | Item Name | File Name | | | | | | Info / Remarks / Notes
| BOARD
1 | Board Name / Number | AMPLIFICATOR AUDIO PUTERE.brd | | | | | | -
2 | Revision Date | 9 November 2018 | | | | | | -
3 | Board Size | 40 x 40 mm² | | | | | | -
4 | Board Quantity | 1 | | | | | | -
5 | Material / Dielectric Type | FR-4 | | | | | | -
6 | Board Thickness | 1.5 mm | | | | | | -
7 | Copper Thickness | 18 μm | | | | | | -
| LAYERS
8 | Number of Electrical Layers | 2 | | | | | | -
9 | Copper Layer TOP | TOP.art | | | | | | -
10 | Copper Layer BOTTOM | BOTTOM.art | | | | | | -
11 | Copper GND Plane | - | | | | | | -
12 | Copper PWR Plane | - | | | | | | -
13 | Copper INNER 1 | - | | | | | | -
14 | Copper INNER 2 | - | | | | | | -
15 | Solder Mask TOP | SMTOP.art | | | | | | -
16 | Solder Mask BOTTOM | SMBOT.art | | | | | | -
17 | Solder Paste TOP | SPTOP.art | | | | | | -
18 | Solder Paste BOTTOM | - | | | | | | -
19 | Peelable Mask TOP | - | | | | | | -
20 | Peelable Mask BOTTOM | - | | | | | | -
21 | Silk Screen TOP | SSTOP.art | | | | | | -
22 | Silk Screen BOTTOM | - | | | | | | -
23 | Board Outline | BO.art | | | | | | -
24 | Fabrication Drawing | FAB.art | | | | | | -
| MILLING & DRILLING
25 | Mill Drawing | - | | | | | | -
26 | Drill Drawing | DRILL.drl | | | | | | -
27 | N.C. Drill (for both PH & NPH) | - | | | | | | -
28 | N.C. Drill / Plated Holes (PH) | - | | | | | | -
29 | N.C. Drill / Non-Plated Holes (PH) | - | | | | | | -
| FINISHING
30 | Panelisation | - | | | | | | -
31 | Electrical Test | - | | | | | | -
32 | Copper Finishing | x | HASL | | OSP | | | ENIG
33 | Board Outline Machining | | Routing | | Milling | | x | V-Cutting
34 | Final remarks | - | | | | -

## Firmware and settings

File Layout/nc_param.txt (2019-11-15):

INTEGER-PLACES         2
DECIMAL-PLACES         5
X-OFFSET               0.000000
Y-OFFSET               0.000000
FEEDRATE               1
COORDINATES            ABSOLUTE
OUTPUT-UNITS           ENGLISH
TOOL-ORDER             INCREASING
REPEAT-CODES           YES
SUPPRESS-LEAD-ZEROES   YES
SUPPRESS-TRAIL-ZEROES  NO
SUPPRESS-EQUAL         YES
TOOL-SELECT            YES
OPTIMIZE_DRILLING      YES
ENHANCED_EXCELLON      YES
TAPE-FILE              C:/Projects/Proiect 1 DCE/P1_2018_432A_Traistaru_Vlad-Viorel_Amplificator_audio_putere_N8_OrCAD/Layout/DRILL.drl
HEADER                 none
LEADER                 12
CODE                   ASCII
SEPARATE               NO
SEPARATE-ROUTING       NO
DRILLING               LAYER-PAIR
BACKDRILL              NO
CAVITY                 NO
COUNTER                NO
TOLERANCE_DRILL        NO
TOLERANCE_TRAVEL       NO
TOOL_SIZE              NO
ROTATION               NO
NON_STANDARD           NO
TOTAL_DRILL            YES
SEPARATE_SLOT          YES
SUPPRESS_TOLERANCE     YES
SUPPRESS_TOOLSIZE      YES
SUPPRESS_ROTATION      YES
